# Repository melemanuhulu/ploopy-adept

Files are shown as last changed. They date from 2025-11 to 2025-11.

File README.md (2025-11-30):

# Ploopy Adept

The [Adept](https://ploopy.co/adept-trackball/) is an powerful open-source trackball by [Ploopy](https://ploopy.co/) running [QMK](https://qmk.fm/).

This repository contains custom 3D models and custom QMK firmware configuration files for the Ploopy Adept trackball.

---

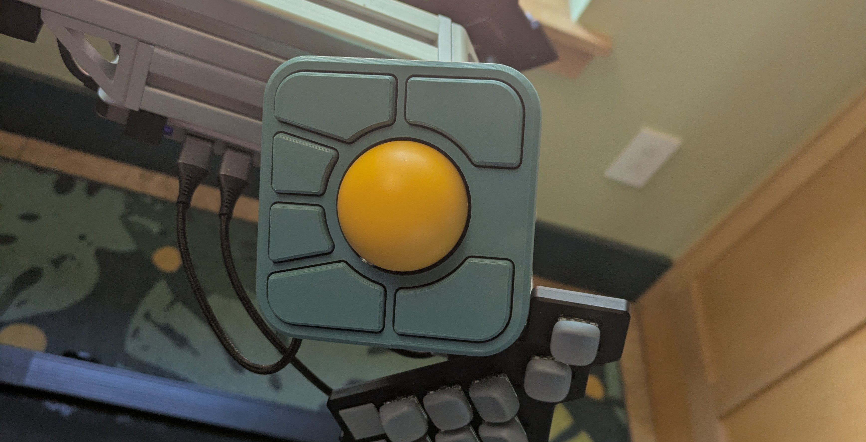
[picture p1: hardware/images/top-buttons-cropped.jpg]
View from the top of the modified Ploopy Adept


The hardware:
 - Is shorter than the original (front-to-back, not top-to-bottom)
 - Has an extra layer that clamps around an L-bracket that can be attached to a ball-head tripod mount for easy adjustments and secure tenting
 - Uses ball transfer units rather than single-axis bearings
 - Has one bearing postioned higher in the shell of the mouse to allow for steeper tenting
 - Uses nuts and bolts to connect layers rather than screws threaded into plastic
 - Has raised buttons that connect to the main body using magnets

---

The firmware includes:
- A custom scroll layer that
  - is accessed by a tap-toggle, allowing for one button on the base layer to be
    - held for momentary scrolling
    - double-tapped to toggle scrolling on
  - can be locked in vertical scroll, horizontal scroll, snap scroll, or unconstrained scroll mode
  - can be used for media control
    - up and down to control volume
    - left and right to scrub
- A navigation layer to open, close, and cycle through open tabs and apps, and a layer to do the same with virtual desktops
- An editing layer with backspace, delete, tab, escape, and enter keys, and quick access to arrow keys
- A files laver with shortcuts to save, search, rename, download, open file browser, select all, print, and print screen
- A cut/copy/paste and browser back/forward/refresh layer
- A 10° offset to so that trackball movements feel natural while maintaining all five fingers in "home positions" on five of the mouse's six buttons
- And more!

---

The hardware and firmware were both designed for a left-handed person. Some modifications will likely be required for ideal use by a right-handed person.

Credit to the fine folk on the [Ploopy Discord](https://discord.gg/qYK9psKrNY) and the maintainers of the [Adept Anyball](https://github.com/adept-anyball) GitHub. Thier ideas and knowledge were very helpful while I was working on this project.

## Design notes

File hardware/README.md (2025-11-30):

# Hardware mod
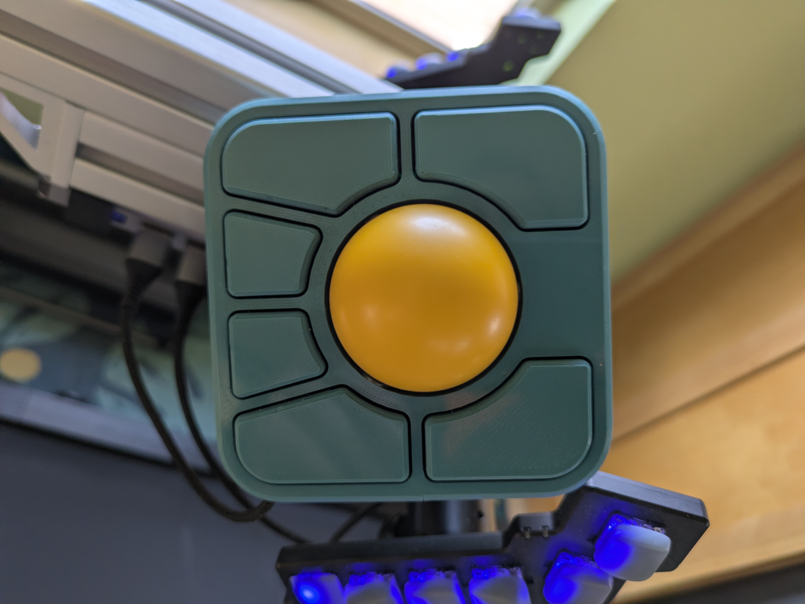
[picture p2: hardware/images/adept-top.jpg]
Top view

The finished product

---

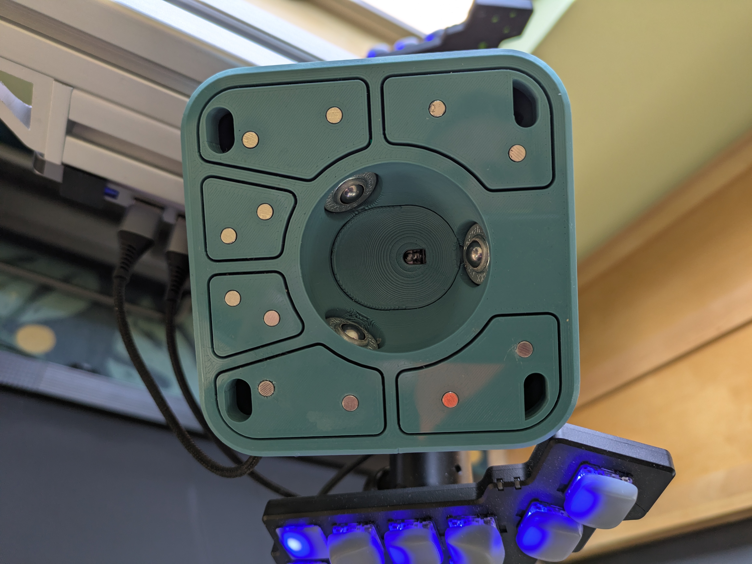
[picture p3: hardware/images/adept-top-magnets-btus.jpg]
Top view with buttons and ball removed

- Single-axis bearings are replaced by spherical ball transfer units
- Magnets are permanently affixed to the top of the shell and the bottom of the buttons by CA glue
- Raised buttons affix to the main body using magnets and are easily swappable
- Access holes allow insertion of hex nuts after printing

---

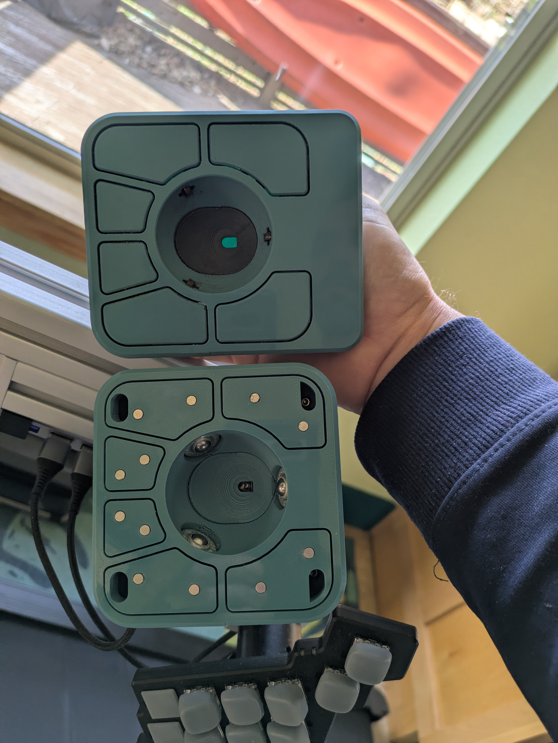
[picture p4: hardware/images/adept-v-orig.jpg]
Comparison with original

Comparison with the original design

---

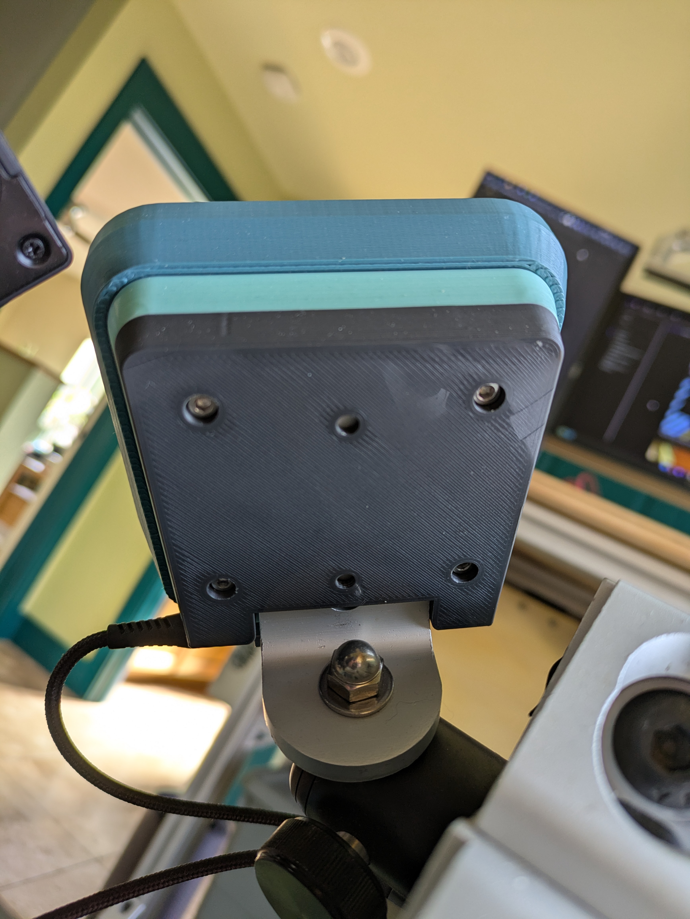
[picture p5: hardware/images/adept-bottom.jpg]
Extra layer

- An L-bracket is sandwiched between two bottom layers, which are held together securely with nuts and bolts
- An acort nut and washer are used to attach the L-bracket to a tripod mount

---

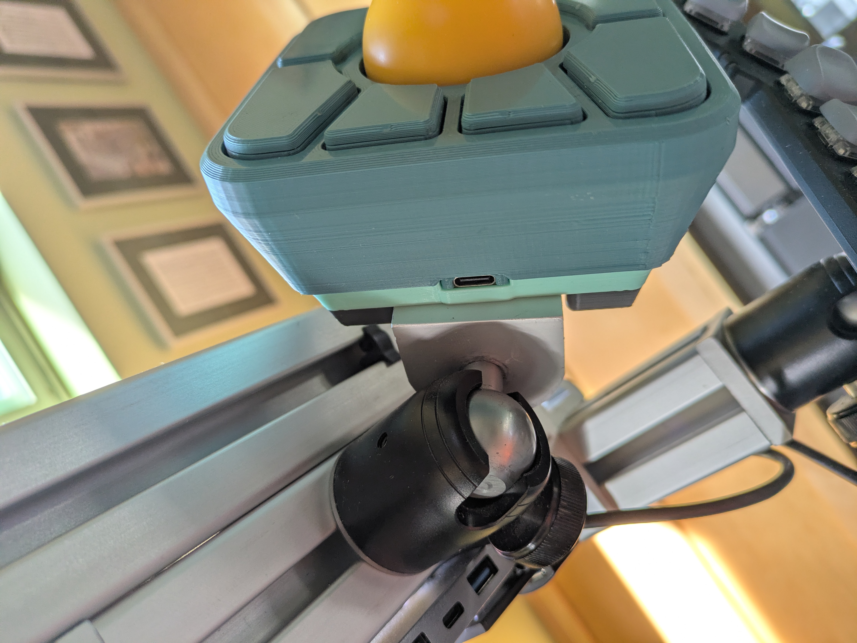
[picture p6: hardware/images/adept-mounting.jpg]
Mounting

A ball-head tripod mount allows for easy adjustment and secure tenting

---

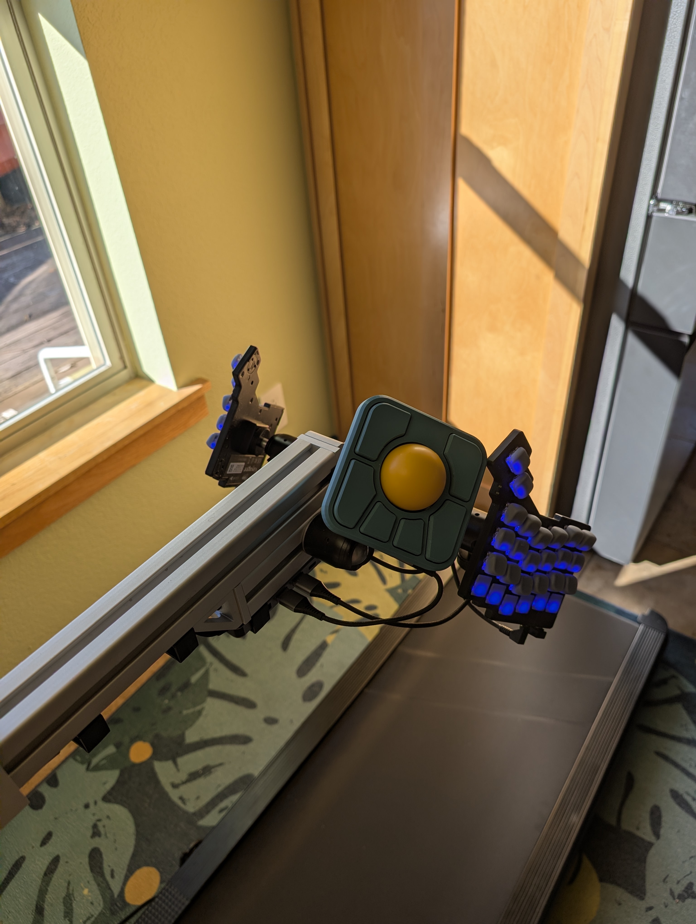
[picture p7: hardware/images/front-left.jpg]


---

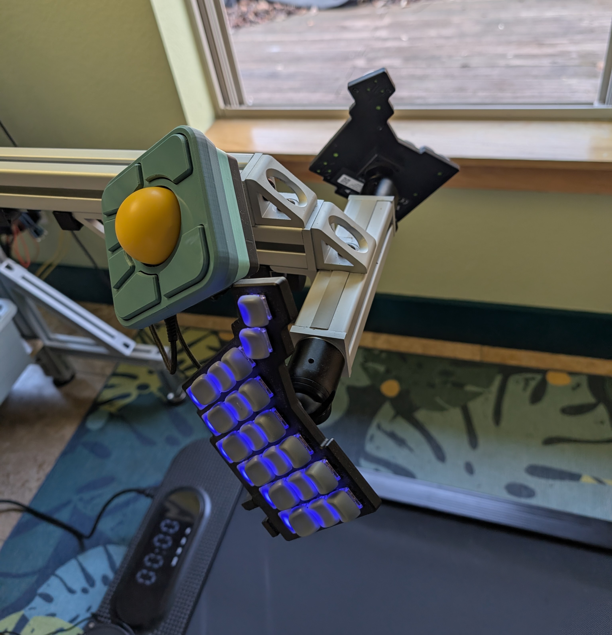
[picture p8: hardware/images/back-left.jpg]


---

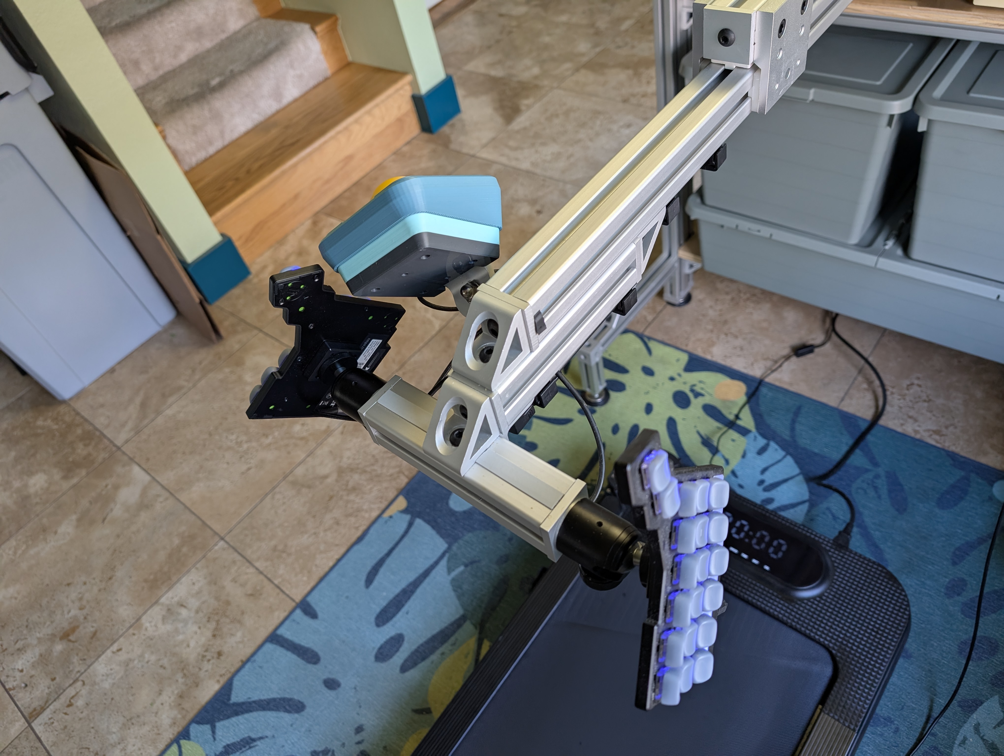
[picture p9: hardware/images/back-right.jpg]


---

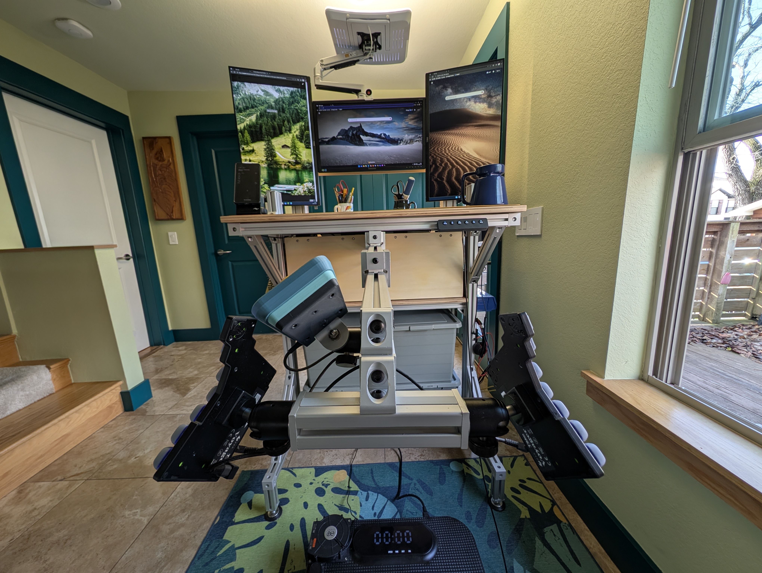
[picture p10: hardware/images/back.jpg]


---

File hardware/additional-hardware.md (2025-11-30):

# Additional Hardware
In addition to using some of the hardware that comes with the original [Ploopy Adept](https://ploopy.co/product-category/trackball/adept/), this mod requires the following:
- (3) [Bosch Rexroth BTUs](https://store.boschrexroth.com/en/us/p/ball-transfer-unit-r053010810)
- (24) 4mm diameter × 2mm thick circular neodymium magnets
- CA glue
- (4) M3 socket head cap screws, 8mm long
- (4) M3 hex nuts
- (4) M2 socket head cap screws, 8mm long
- (4) M2 hex nuts
- (1) [L-bracket](https://8020.net/4349.html)
- (1) standard ball-head tripod mount with 1/4-20 screw
- (1) 1/4-20 acorn nut to secure the L-bracket to the tripod mount
- (1) small washer to go between the acorn nut and the L-bracket
- Hardware to connect the tripod mount to the desk/work surface may be required and will vary depending on the desk/work surface

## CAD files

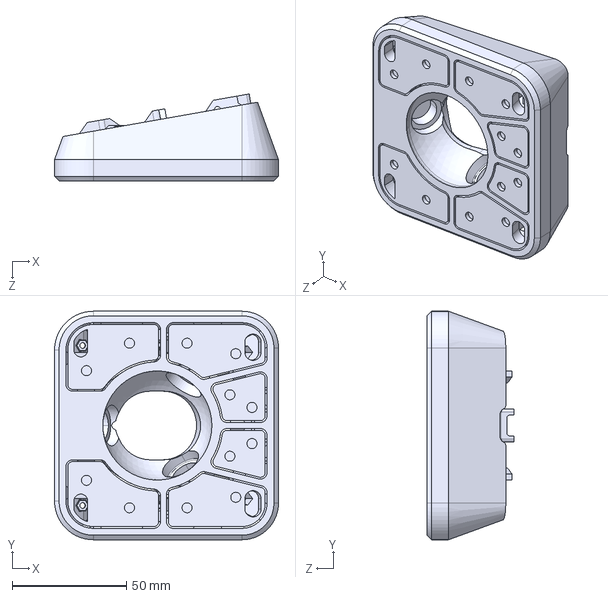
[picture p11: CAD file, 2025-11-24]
hardware/individual-parts/top.STEP
98.0 x 100.0 x 38.1 mm

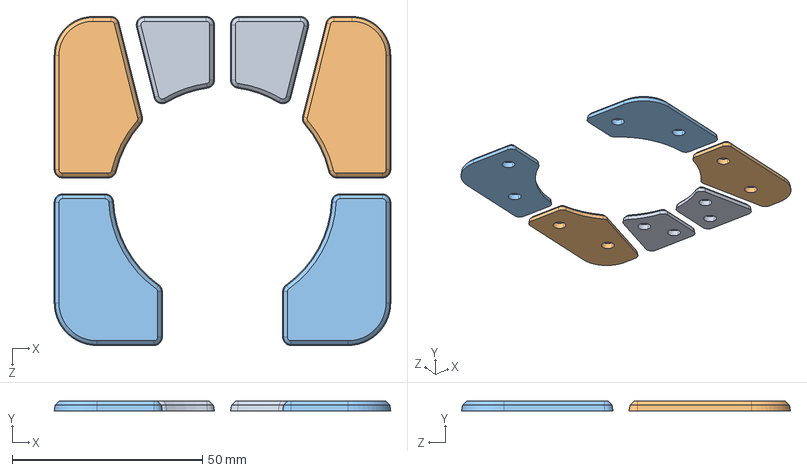
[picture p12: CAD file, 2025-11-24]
hardware/individual-parts/buttons.STEP
88.4 x 2.50 x 86.4 mm

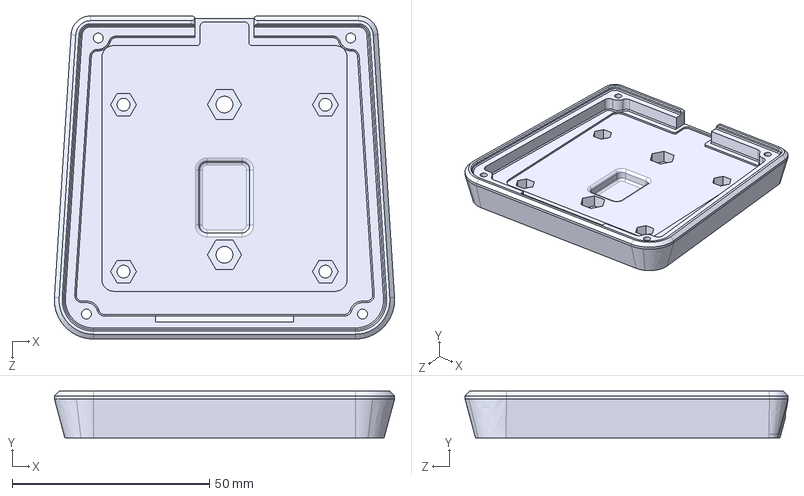
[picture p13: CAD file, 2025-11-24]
hardware/individual-parts/middle.STEP
86.3 x 11.9 x 81.9 mm

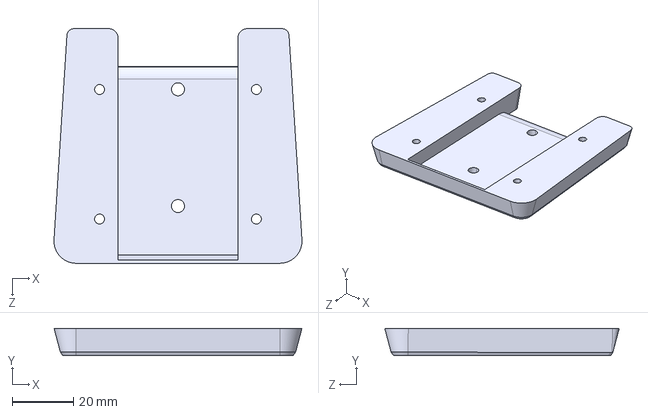
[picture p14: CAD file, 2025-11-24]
hardware/individual-parts/bottom.STEP
81.0 x 8.94 x 76.6 mm

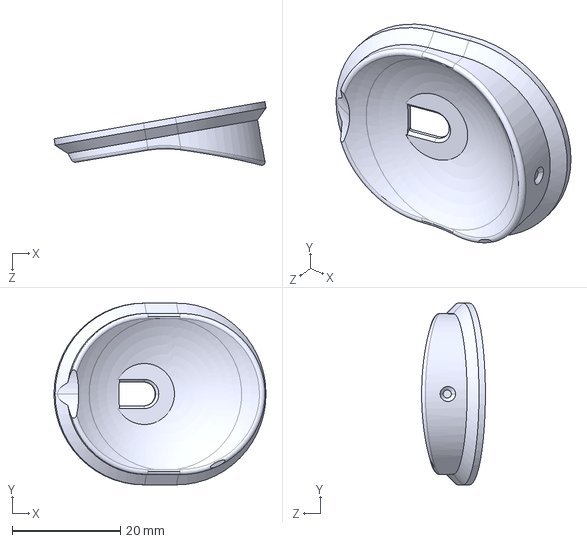
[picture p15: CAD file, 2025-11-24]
hardware/individual-parts/underBall.STEP
39.2 x 33.6 x 11.8 mm

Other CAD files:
hardware/individual-parts/bottom.SLDPRT
hardware/individual-parts/buttons.SLDPRT
hardware/individual-parts/middle.SLDPRT
hardware/individual-parts/top.SLDPRT
hardware/individual-parts/underBall.SLDPRT

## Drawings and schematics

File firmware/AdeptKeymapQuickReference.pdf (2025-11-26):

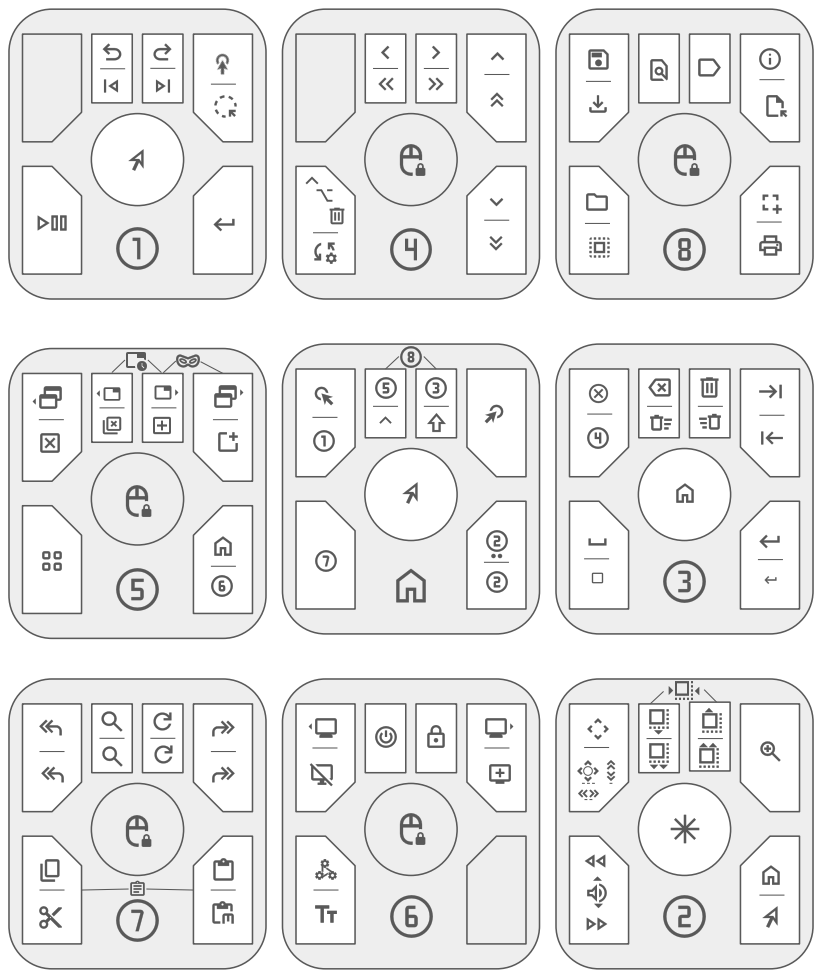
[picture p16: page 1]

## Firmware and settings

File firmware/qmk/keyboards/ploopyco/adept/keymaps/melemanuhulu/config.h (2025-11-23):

/* Copyright 2023 Colin Lam (Ploopy Corporation)
 * Copyright 2020 Christopher Courtney, aka Drashna Jael're  (@drashna) <drashna@live.com>
 * Copyright 2019 Sunjun Kim
 *
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
 * You should have received a copy of the GNU General Public License
 * along with this program.  If not, see <http://www.gnu.org/licenses/>.
 */

#pragma once

#define UNUSABLE_PINS \
    { GP1, GP3, GP4, GP6, GP8, GP10, GP14, GP16, GP18, GP20, GP22, GP24, GP25, GP26, GP27, GP28, GP29 }

//#define ROTATIONAL_TRANSFORM_ANGLE 0
//#define POINTING_DEVICE_INVERT_Y

// PMW3360 Settings
#define PMW33XX_LIFTOFF_DISTANCE 0x00
#define PMW33XX_CS_PIN GP5
#define PMW33XX_CPI 800
#define SPI_SCK_PIN GP2
#define SPI_MISO_PIN GP0
#define SPI_MOSI_PIN GP7

//High-resolution scrolling
#define POINTING_DEVICE_HIRES_SCROLL_ENABLE 0
#define POINTING_DEVICE_HIRES_SCROLL_MULTIPLIER 64
//#define PLOOPY_DRAGSCROLL_DIVISOR_H 4.0 //Sets the horizontal movement divisor to use when drag scroll is enabled.
//#define PLOOPY_DRAGSCROLL_DIVISOR_V 4.0 //Sets the vertical movement divisor to use when drag scroll is enabled

//Use for non-high-res scrolling
//#define PLOOPY_DRAGSCROLL_DIVISOR_H 100.0 //Sets the horizontal movement divisor to use when drag scroll is enabled.
//#define PLOOPY_DRAGSCROLL_DIVISOR_V 100.0 //Sets the vertical movement divisor to use when drag scroll is enabled

/* melemanuhulu settings */
#define ONESHOT_TIMEOUT 1000  // Timeout in milliseconds
#define TAPPING_TOGGLE 2
//#define PLOOPY_DRAGSCROLL_MOMENTARY
//#define PLOOPY_DRAGSCROLL_INVERT

#define ROTATIONAL_TRANSFORM_ANGLE 10	//Account for mouse angle

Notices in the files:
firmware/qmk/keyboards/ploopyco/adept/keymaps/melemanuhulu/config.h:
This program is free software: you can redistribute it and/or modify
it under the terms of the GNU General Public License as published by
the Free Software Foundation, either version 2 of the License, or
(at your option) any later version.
